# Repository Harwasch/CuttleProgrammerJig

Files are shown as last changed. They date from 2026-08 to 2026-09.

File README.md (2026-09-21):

# Cuttle CANServo_Driver — SWD pogo programming jig

A 3D-printed spring-nest fixture for flashing the Cuttle CAN servo driver
board over SWD, using P50-B1 pogo probes against the seven bare-copper test
points on the underside of the board. No PCB required — five printed parts,
four springs, seven probes and a GH-201 toggle clamp.

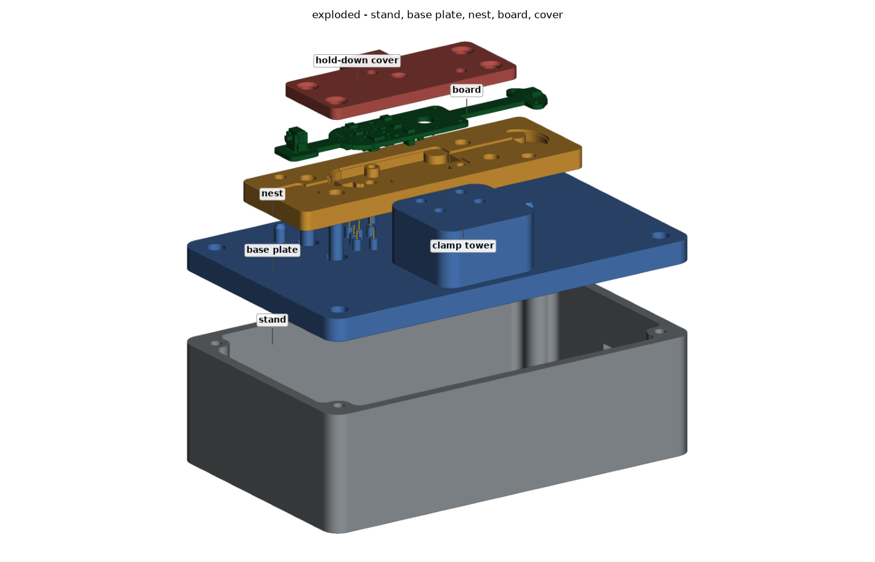
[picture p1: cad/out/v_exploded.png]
assembly


## How it works

The board never has to be pushed onto exposed probe tips by hand:

1. A **nest** floats 3 mm above the base on four springs. The probe tips sit
   **1.8 mm below** the board when the clamp is open, so the board drops in
   freely and locates on two pins through its own 2.2 mm holes.
2. Closing the clamp pushes a **hold-down cover** down onto nine pads that
   land on bare board, driving the nest onto a hard stop.
3. At the stop the nest has travelled exactly 3 mm, which compresses each
   probe **1.20 mm** — 45 % of the P50's 2.65 mm stroke.

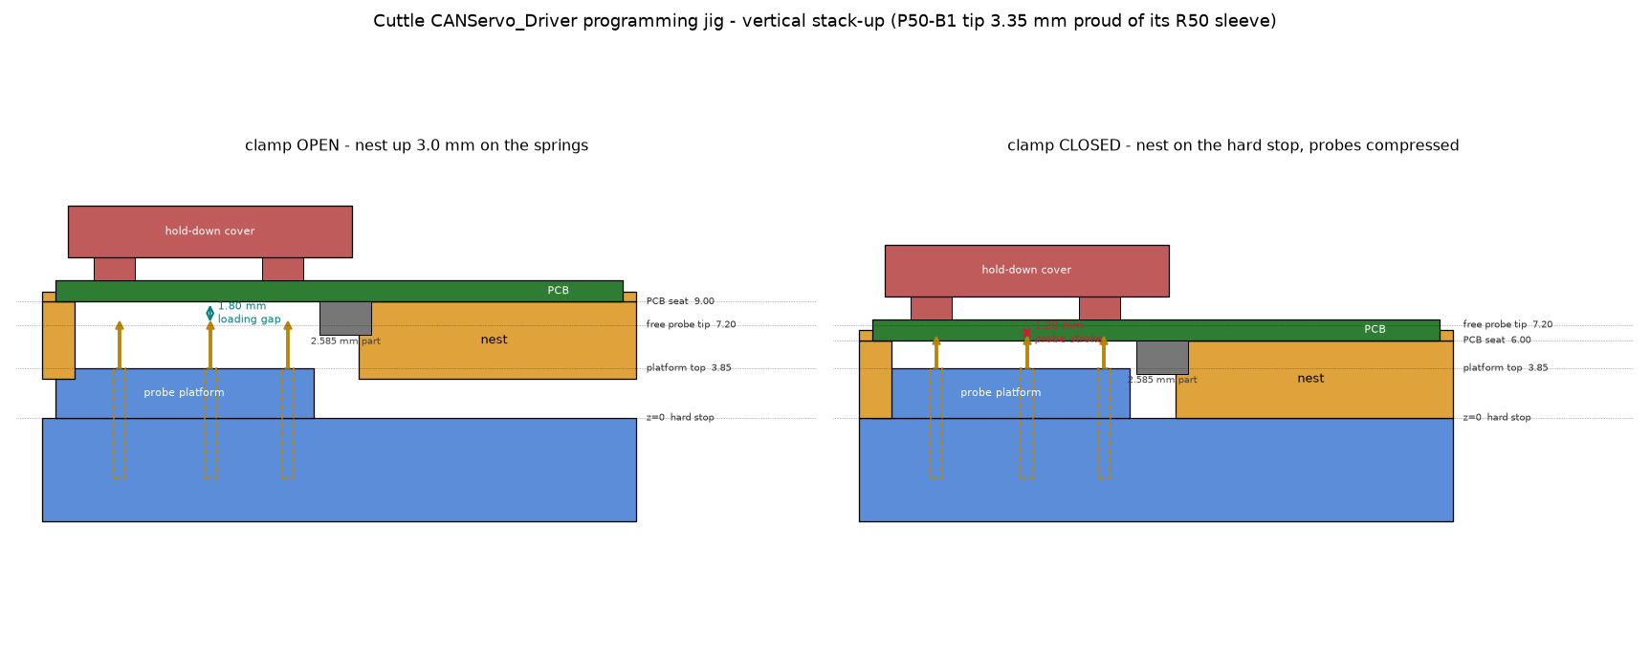
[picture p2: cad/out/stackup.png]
stack-up


## The board

Everything below was extracted from the V0.4 gerbers and the KiCad STEP
export, not typed in by hand — see [`cad/tools/`](cad/tools). The board is a
6-layer rigid-flex, 104.6 × 20.1 mm, 1.627 mm thick, in three rigid sections
joined by two 6 mm flex necks. The jig supports all three flat so the flex is
never bent during programming.

The seven test points are **bare copper discs with solder-mask openings**, not
pad footprints — Ø1.2 mm, all on the bottom layer (L6):

| Net | X | Y | note |
|---|---:|---:|---|
| NRST | −32.25 | +1.70 | 1.42 mm from the board edge |
| GND | −28.25 | −6.30 | |
| SWO | −26.25 | −1.70 | |
| VDD_3V3 | −23.45 | +5.40 | |
| VDD_3V3 | −23.15 | −8.80 | 1.12 mm from the board edge |
| SWDIO | −22.25 | +1.30 | |
| SWCLK | −17.15 | +1.90 | |

Coordinates are in the jig frame: origin at the centroid of the four Ø2.2 mm
holes on the main rigid section, +Y up. Those four holes are the motor /
connector pattern, not board-mounting holes; the jig borrows two of them
(diagonal, 29.6 mm apart) purely to locate the board.

The nest does not try to thread a support surface between the components.
It seats the board on six bosses at its own mounting holes plus the three
sections that carry **no bottom-side parts at all** — the SWD tab and both flex
necks — and drops everything else in one pocket. A boss under the MCU stops
0.1 mm short of the package, backing the board against probe force without
lifting it off its seat. Nothing on the part is thinner than 3 mm.

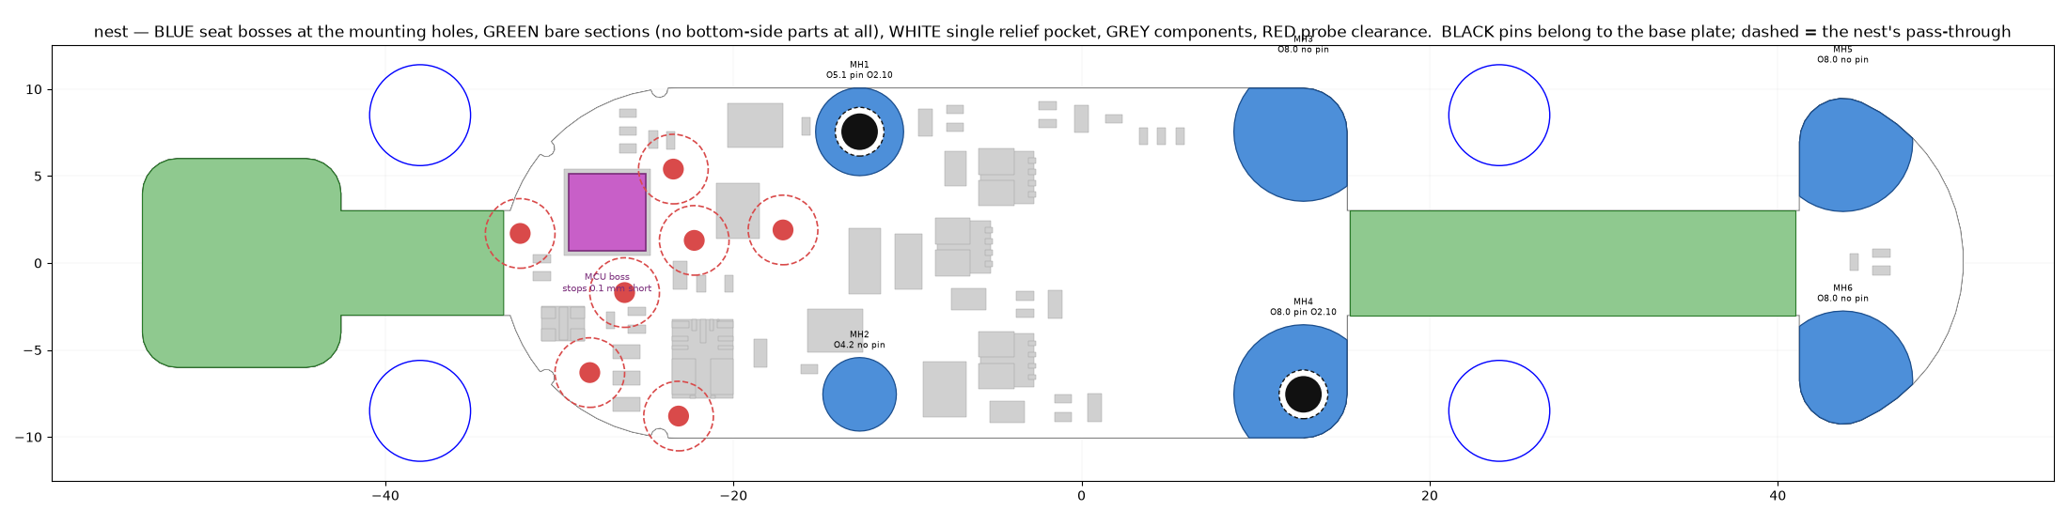
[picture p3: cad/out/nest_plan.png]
nest plan


## Views

| | |
|---|---|
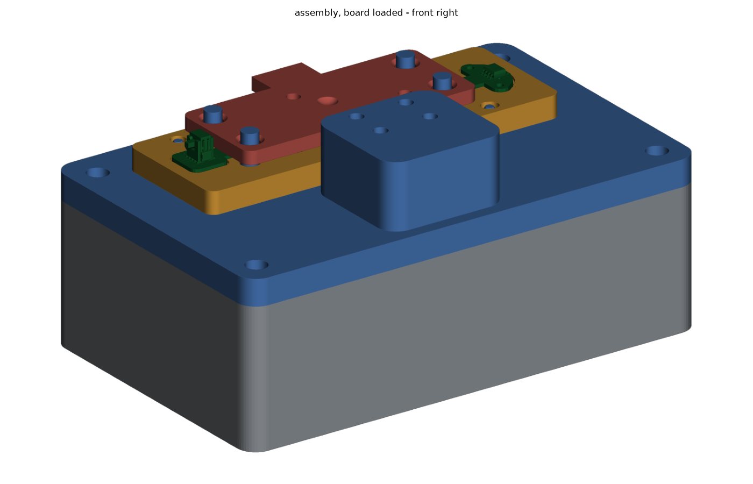
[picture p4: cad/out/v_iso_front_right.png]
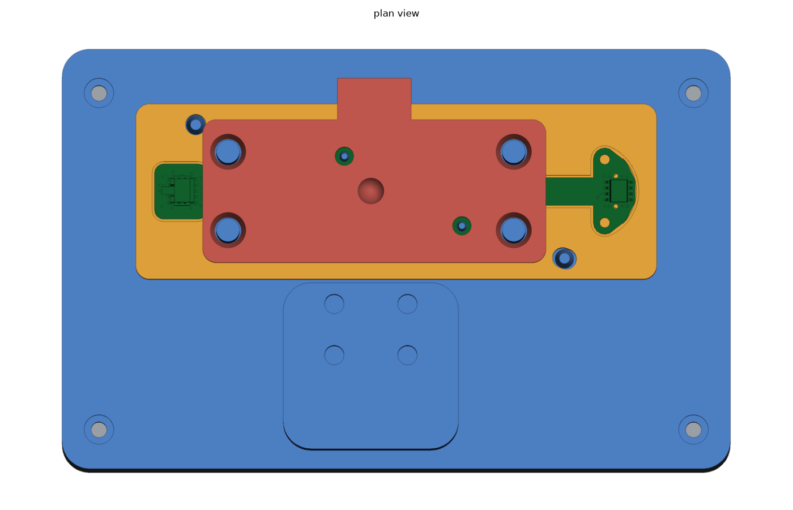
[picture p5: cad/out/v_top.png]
|  |  |
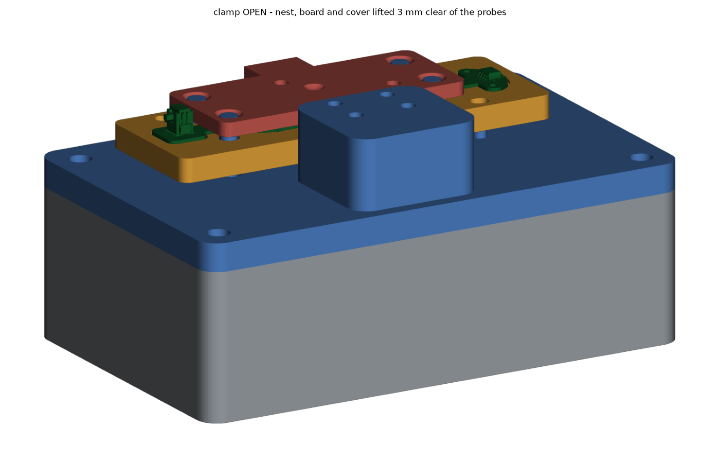
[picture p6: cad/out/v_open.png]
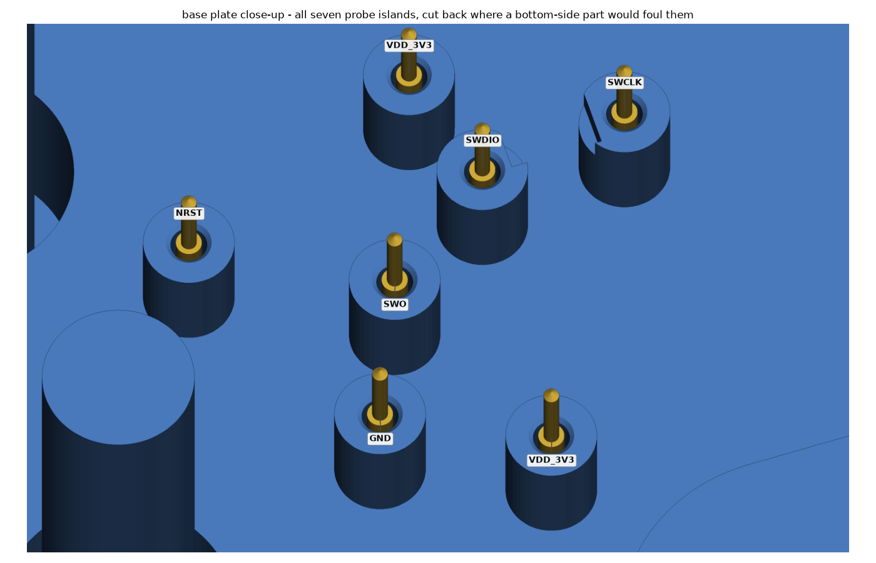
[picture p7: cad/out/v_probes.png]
|  |  |
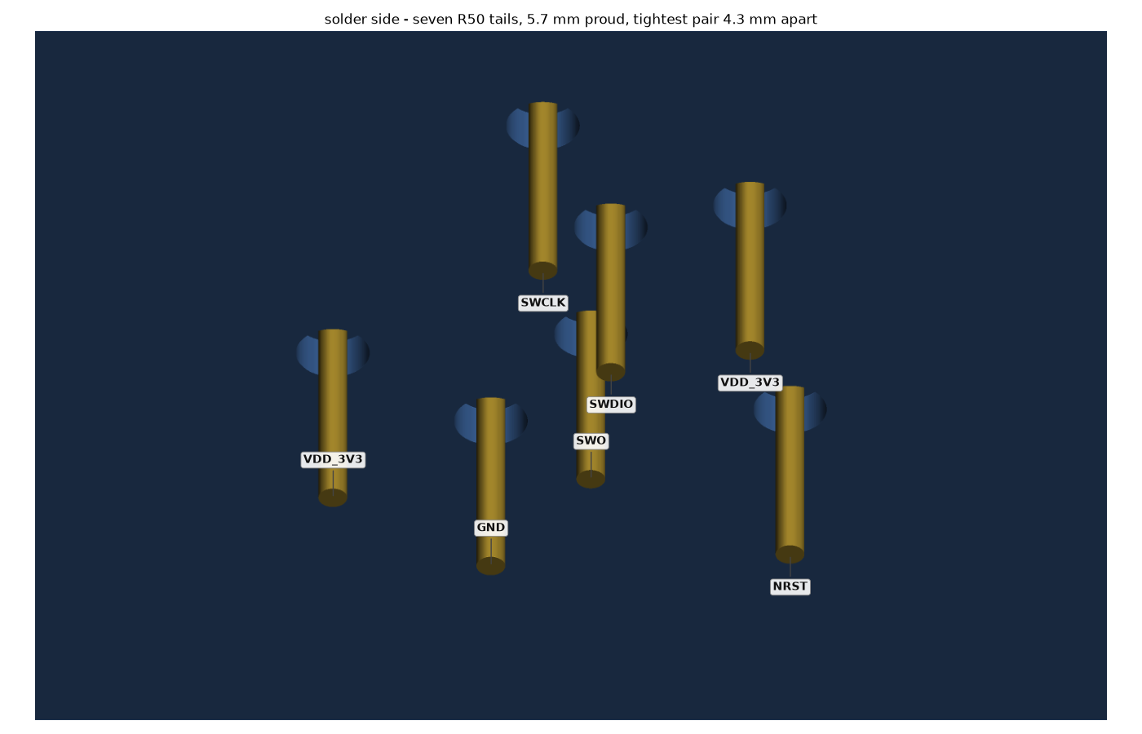
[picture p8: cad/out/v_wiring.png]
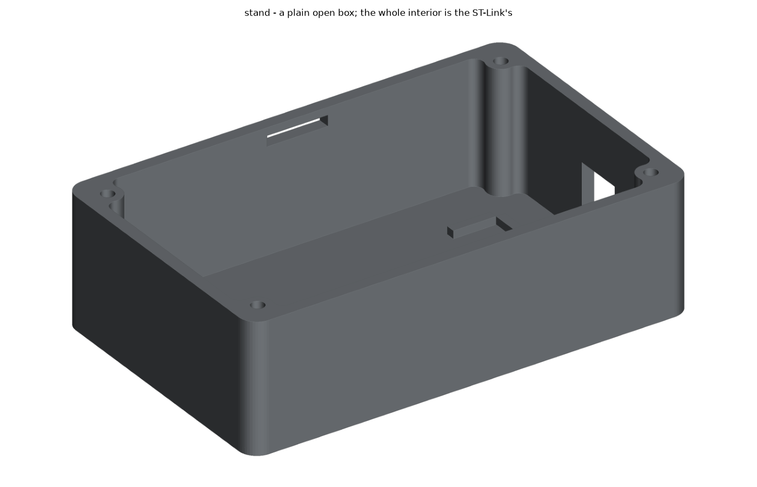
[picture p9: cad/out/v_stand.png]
|  |  |
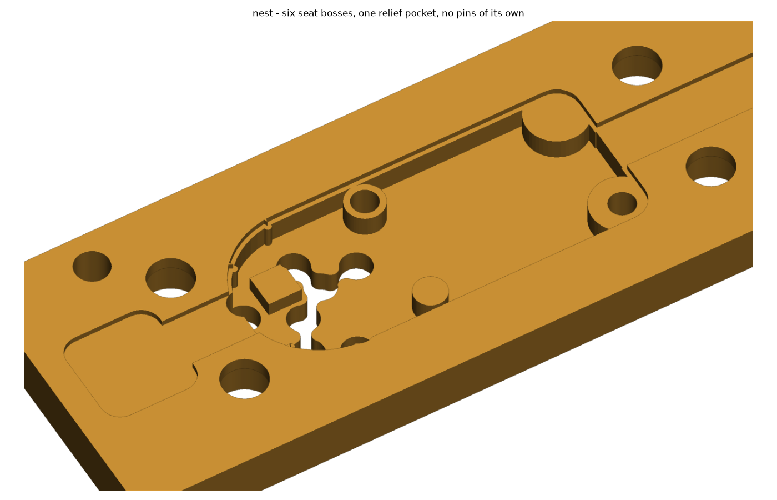
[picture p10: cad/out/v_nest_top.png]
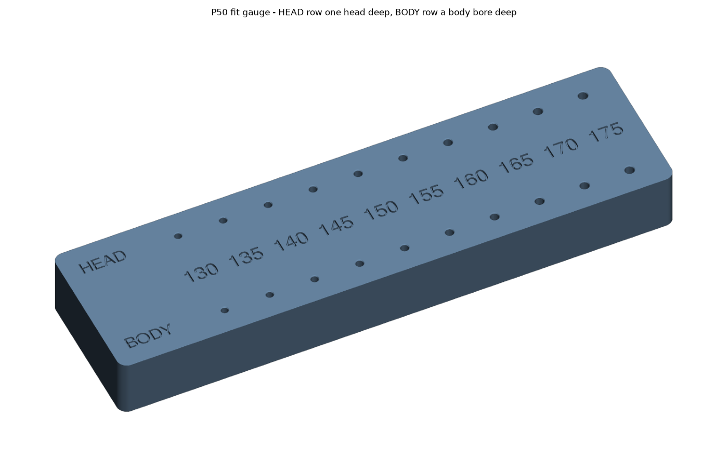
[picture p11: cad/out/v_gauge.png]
|  |  |

`python3 tools/render.py` regenerates all fifteen; `python3 tools/render.py top
probes` does just those. The renderer is a small software z-buffer rasteriser
(orthographic, backface-culled, 2x supersampled, with a depth-discontinuity
outline pass) — a painter's-algorithm sort mis-orders the stand's large flat
faces against the base plate.

## Parts

| Part | Print | Notes |
|---|---|---|
| `base_plate` | flat, features up | The precision part, and the lid of the stand: 7 probe bores, 4 guide posts, 2 stepped board locators, 2 registration pins, spring pockets, and the clamp tower |
| `stand` | as modelled | A plain open box. Its whole 137 × 83 × 40 mm interior is the ST-Link's |
| `nest` | flat | Six seat bosses, one relief pocket, pass-throughs for the locator and registration pins |
| `cover` | pads up | Hold-down; presses only on bare board, rides all four posts, pressed on the centre of the spring quad |
| `fit_gauge` | flat | Calibration coupon; print once to set the probe bore size |

STEP and STL for all of them are in [`cad/out/`](cad/out).

## Getting started

Build instructions, bill of materials, the bore calibration step and the wiring table
are in **[docs/BUILD.md](docs/BUILD.md)**.

To regenerate everything after changing a dimension:

```bash
cd cad
python3 jig.py        # writes STEP + STL into cad/out/
python3 verify.py     # 159 interference, fit and printability checks
```

`verify.py` checks the parts against a keep-out solid built from the real
component heights. That solid uses each component's bounding box, so it is
strictly larger than the parts themselves — a clean result is a proof of
clearance, not a sample of it. `extract_parts.py` refuses to emit a model that
would leave any board-spanning solid unaccounted for, which is what makes the
conservative claim hold. `python3 verify.py --full` re-runs the same checks
against the STEP export's own solids if you want exact shapes rather than
bounding boxes. It takes about twenty minutes.

Both paths test the same population — components. `--full` excludes copper
film (pads, via rings, plating) on the same `FILM_T` rule the extractor uses;
without that it reported the 45 bottom-side copper pads the board rests on as
a 0.28 mm³ interference, which every PCB has and no jig can avoid.

The `--full` path was silently broken until recently: a `Location` on a
`Compound` is ignored by `.intersect()`, so it was measuring the board at its
raw gerber coordinates and reporting four failures that were pure artefact —
with identical volumes before and after a 3 mm lift, which no real boolean can
produce. If you are reading an older revision, do not trust its output.

## Larger pogo pins

`JIG_PINS=P100 python3 jig.py` builds the same jig for a **P100-B1 probe in an
R100-4S receptacle** instead of the default P50/R50 pair, into `cad/out/p100/`.
It is a new `base_plate`, `stand` and `fit_gauge`; the `nest` and `cover` carry
straight over. Its gauge also gave the design a second hole-shrink calibration
point — 0.10 mm at Ø2.0 against 0.22 mm at Ø1.2 — so the print model
interpolates with diameter instead of using one constant. Both variants build and verify from the same code, and
`cad/tools/compare_families.py` reports which parts actually differ. See
[docs/BUILD.md](docs/BUILD.md) for why the bigger pin also moves the ST-Link.

## Magnet test fixture

[`magfixture/`](magfixture) is a separate fixture for the same board: it holds
it flat and presents a spinning magnet to the AS5600L rotary encoder and a
magnet adjustable from 1 to 13 mm to the linear hall sensor. It reuses this
package's board geometry and print model rather than keeping its own copy.

## Board source files

`cad/ref/` holds the inputs the extractors read — the V0.4 gerbers and the
KiCad STEP export — and is **git-ignored on purpose**: this repository is
public and the servo board repository is not. Copy them in locally before
re-running the extractors. The derived `board_geometry.json` and
`board_parts.json` that `jig.py` actually builds from are committed.

## Retargeting to a new board revision

```bash
cd cad/tools
python3 extract_board.py   # outline, cutouts, test points  <- gerbers
python3 extract_parts.py   # component keep-outs            <- STEP
cd .. && python3 jig.py && python3 verify.py
```

Nothing in `jig.py` hard-codes board geometry; it all comes from
`board_geometry.json` and `board_parts.json`.

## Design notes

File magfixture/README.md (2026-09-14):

# Magnet test fixture — Cuttle CANServo_Driver V0.4

Holds the board flat and presents a magnet to each of its two magnetic
sensors, so both can be exercised on the bench.

| sensor | package | centre | package top |
|---|---|---|---|
| **AS5600L** rotary encoder | SOIC-8 | (+46.81, +0.10) | 1.838 mm above the board |
| **SOT-23** linear hall | 3-pin | (−23.25, +0.07) | 1.285 mm above the board |

Both positions are **measured**, not transcribed: the KiCad STEP export carries
each component's footprint name as a label, and `tools/find_sensors.py` reads
them straight out of it. The package *heights* come from `cad/board_parts.json`
— the same keep-out data the interference checks use — so the airgap the
fixture builds and the airgap the checks measure cannot disagree.

## What it does

**Encoder.** A Ø6 × 2.5 mm diametric magnet in a rotor, journalled directly
over the package and spun by finger. The airgap is **1.00 mm** face to package,
inside the AS5600 datasheet's 0.5–3.0 mm window, and it is set by the rotor's
own shaft length against a knob that lands on the journal hub — nothing to
adjust, nothing to measure. The magnet stays within **0.242 mm** of the die
centre worst case, inside the datasheet's ±0.25 mm.

**Linear hall.** A magnet on a sleeve running on one column, adjustable from
**1 mm to 13 mm** face-to-face.

It takes **any of three magnets** — Ø6, Ø10 or Ø13 — all seating on the same
face datum. The Ø13 presses straight into the sleeve pocket; the smaller two go
in via a press-in adapter ring. A stepped pocket would have been simpler but is
exactly wrong here: the smallest magnet would end up highest, and it is the one
that has to reach 1 mm from the package. A Ø4 hole through the pocket ceiling
pushes any of them back out — you cannot pull a neodymium magnet out of a blind
hole.

## What changed, and why

**One part, not three.** The plate, the hall column and the encoder portal are
now a single printed body. The encoder stand used to bolt on, which was a thing
to lose and a stack-up between the magnet and the board.

**A column, not posts.** Two Ø6 × 30 mm free-standing cylinders snapped at the
root, and they were always going to: a printed cylinder lays its layer bonds
square across the bending load, offers 42 mm³ of section modulus between them,
and cannot be flared into the plate. The 14 × 10 mm column carries **228 mm³**
— 1.09 MPa at the root under a 10 N shove at the top of its travel, a 23×
margin on PETG's layer-bond strength — resists twist without needing a second
member, and sits on a gusset that spreads the root stress instead of
concentrating it in one layer line.

**A portal, not a cantilever.** The encoder reach used to be a 9 mm ledge
anchored on one side. Two walls carry a deck, so the deck's underside is a true
bridge anchored at both ends.

**A dowel and a diamond on the lobe.** The lobe pins needed a pin radius of
freedom along the line joining them. *Moving* them together by that much does
not give it — the lobe's hole pitch is 13.723 mm and fixed inside the rigid
lobe, the pins print Ø2.10 in a routed Ø2.20, so a 1.010 mm pitch change leaves
the second pin missing its hole by 0.960 mm and the lobe will not go on at all.
Dowel-and-diamond does give it: **MH5 is a round pin and is the datum**, MH6 is
relieved to 1.09 mm along the pitch line and stays full width across it, so the
pair floats **±0.555 mm** on pitch while still stopping the lobe rotating.

And since the main section is on the far side of a flex neck — where the
lamination, not the drawing, decides where it ends up — the **lobe** is the
datum and MH1/MH4 are undersize (Ø1.80, 0.20 mm radial) so the main section
follows it instead of fighting it. The encoder is the tight requirement; a hall
magnet 6 to 13 mm across does not care about a fifth of a millimetre.

## Bill of materials

| Qty | Item | Notes |
|---:|---|---|
| 1 | Ø6 × 2.5 mm magnet, **diametric** | encoder — must be diametrically magnetised or the AS5600 reads nothing useful |
| 1 | Ø6 × 2.5, Ø10 or Ø13 magnet, **axial** | linear hall |
| 1 | M3 heat-set insert, 4 mm | sleeve clamp |
| 1 | M3 × 16 thumbscrew | clamps the sleeve to the column |

## Parts

| Part | Print | Notes |
|---|---|---|
| `fixture_body` | flat, features up | Plate, relief pocket, four locating pins, hall column, encoder portal |
| `rotor` | **inverted**, knob down | Ø9 body, Ø6 magnet pocket |
| `hall_sleeve` | flat, arm underside down | Rectangular bore, Ø13 pocket opening downward |
| `ring_10`, `ring_6` | flat | Press-in adapters |
| `gap_gauge` | flat | One tongue per separation |

No supports on anything. Worst bridge is **11.0 mm of half-span** (the portal
deck, anchored on both walls); nothing anywhere is an unanchored ledge.

## Assembly

1. Press the encoder magnet into the rotor until its face is flush with the
   rotor's bottom. **Check the polarity is diametric** — it should attract and
   repel a second magnet around its circumference, not through its faces.
2. Drop the rotor down through the portal's journal from above. The knob cannot
   follow it through; it lands on the hub and sets the airgap.
3. Melt the M3 insert into the sleeve's clamp boss and fit the thumbscrew.
4. Press the hall magnet into the sleeve pocket, face flush with the sleeve's
   underside — directly for Ø13, through `ring_10` or `ring_6` otherwise. Press
   the ring in flush first, then the magnet into the ring.
5. Slide the sleeve down onto the column.

## Using it

Lift the rotor out, slide the board's lobe under the portal deck, and let the
board down onto its four pins — MH5 first, which is the datum. Drop the rotor
back in.

**Encoder:** turn the knob. Nothing to set.

**Linear hall:** slacken the thumbscrew, slip the gap gauge's step between the
magnet face and the package, let the sleeve down onto it, tighten, withdraw the
gauge. That sets the separation by a printed dimension you can check with
calipers rather than by reading a scale — and it makes sleeve tilt irrelevant
to the number you end up with. Steps are 1, 2, 3, 4, 5, 6, 8, 10 and 13 mm.

To take the board out: lift the rotor, lift the board clear of its pins (3.6 mm,
against 6.5 mm of headroom under the deck), slide it out in −X.

## Checks

```bash
cd magfixture
python3 fixture.py      # STEP + STL into out/
python3 verify.py       # 62 checks
python3 tools/render.py
```

`verify.py` measures sensor targeting, sleeve travel and its clearance to the
PCBA across the whole sweep, every fit as printed, board seating, and
overhangs in each part's print orientation. It shares the board geometry and
the print model with the programming jig in [`../cad`](../cad) rather than
keeping a second copy that can drift.

The printability check tells **bridges from cantilevers**, which the jig's
version does not: it collects overhang area per tessellated triangle, takes the
part's own plan section 0.5 mm below as the support, and counts a patch as
bridged only where it lies inside the convex hull of that section. A bridge is
anchored at both ends and the filament goes into tension; a cantilever has a
free end and curls after a few millimetres. Treating both as "the widest
downward face" is what let a 9 mm one-sided ledge through, and what let the gap
gauge's tongues stick 14 mm into thin air.

## Measure these before printing

`HALL_MAG_T_MAX` (8 mm) is the deepest hall magnet the pocket takes — check
yours fits, since you may use a Ø10 or Ø13 of unknown thickness. Everything
else is driven by the board's own STEP or by the AS5600 datasheet.

If your board drops onto full-size pins at both lobe holes, set
`LOBE_PIN_PULL_IN = 0.0` in `mag_params.py`: MH6 becomes a round pin too, and
the lobe is then located to 0.05 mm instead of 0.555 mm.

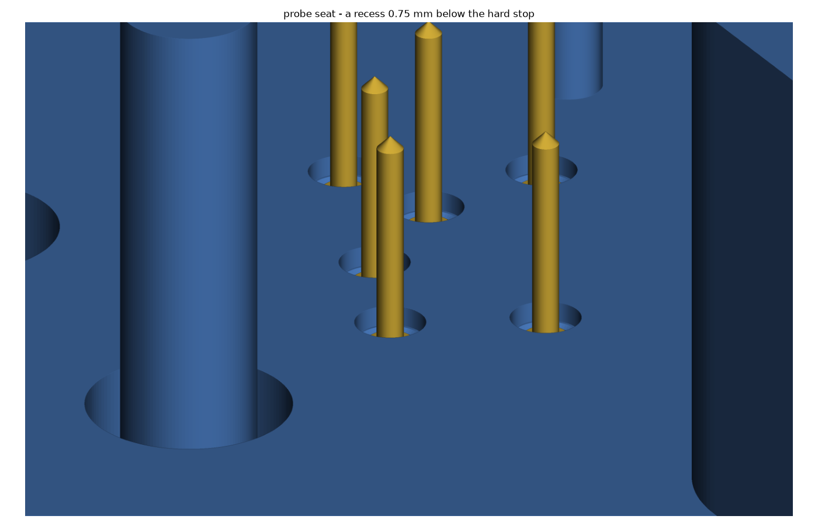
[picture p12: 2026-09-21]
cad/out/p100/v_seat.png

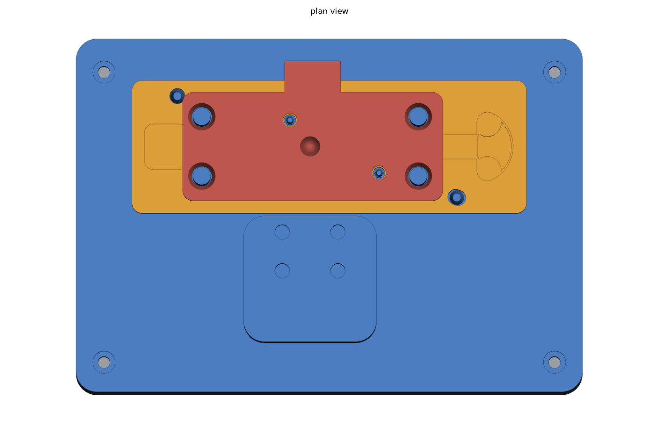
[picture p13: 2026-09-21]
cad/out/p100/v_top.png

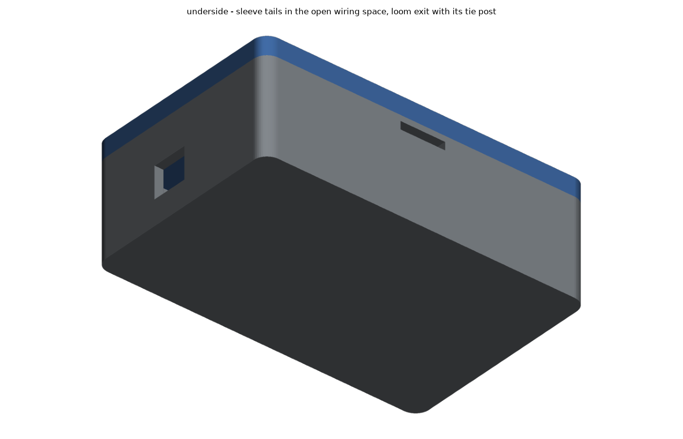
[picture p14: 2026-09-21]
cad/out/v_underside.png

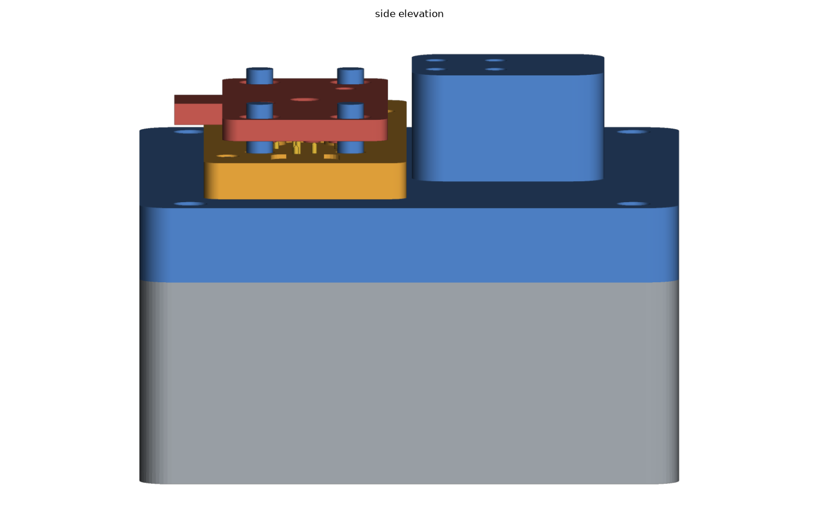
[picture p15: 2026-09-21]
cad/out/p100/v_side.png

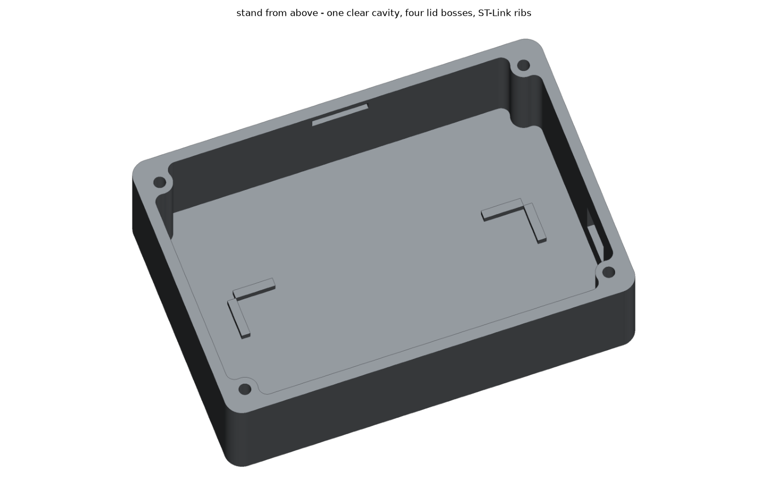
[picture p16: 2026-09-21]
cad/out/p100/v_stand_top.png

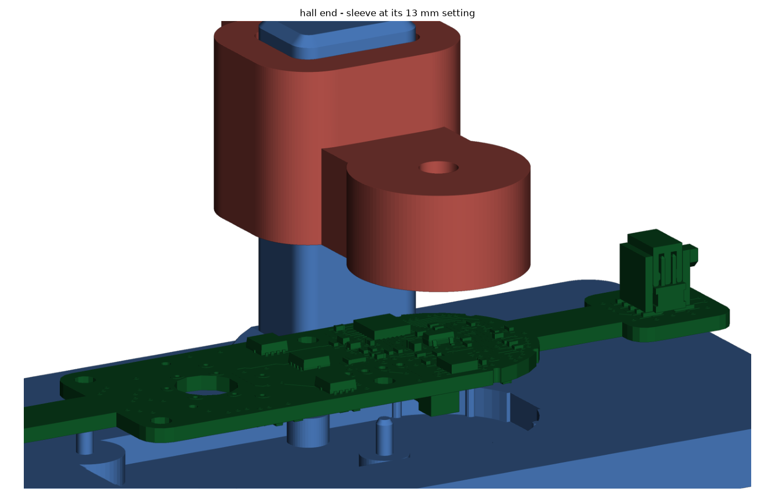
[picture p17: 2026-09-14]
magfixture/out/v_hall_far.png

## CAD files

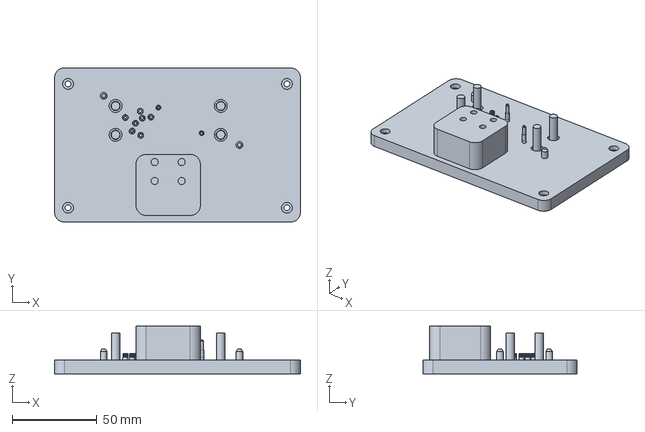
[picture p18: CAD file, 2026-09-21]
cad/out/base_plate.step
145.0 x 91.0 x 28.0 mm

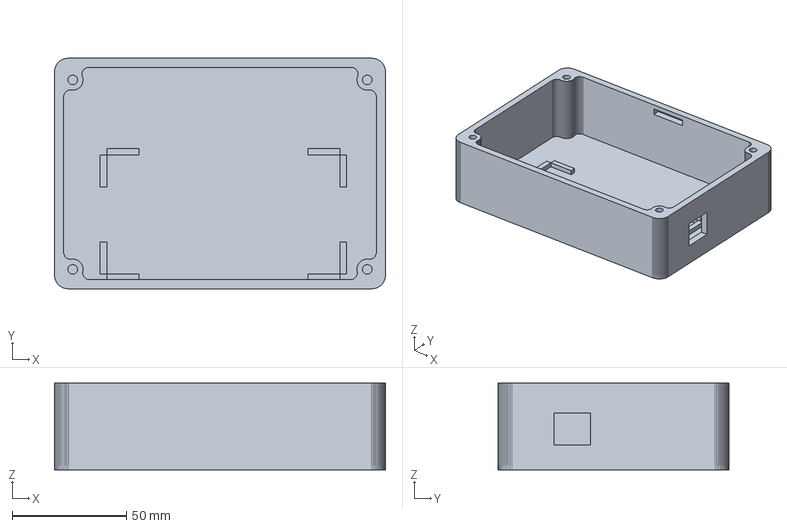
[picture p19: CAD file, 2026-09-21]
cad/out/p100/stand.step
145.0 x 101.0 x 38.0 mm

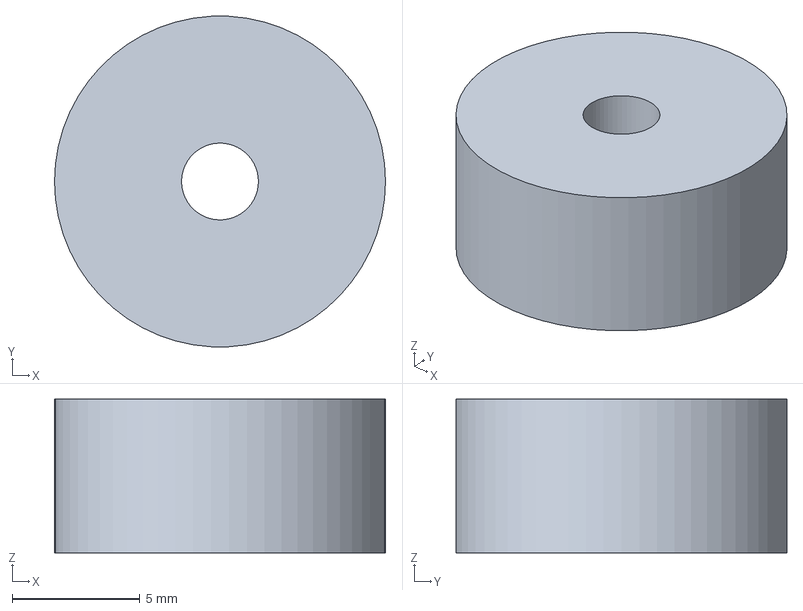
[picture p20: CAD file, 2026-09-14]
magfixture/out/ring_6.step
12.9 x 12.9 x 6.00 mm

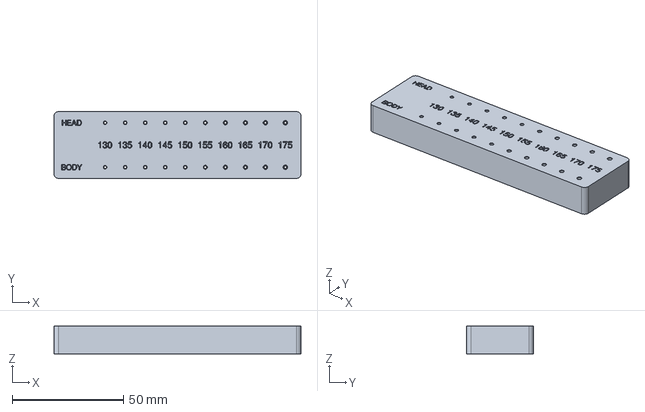
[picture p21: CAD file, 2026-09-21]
cad/out/fit_gauge.step
111.0 x 30.0 x 12.5 mm

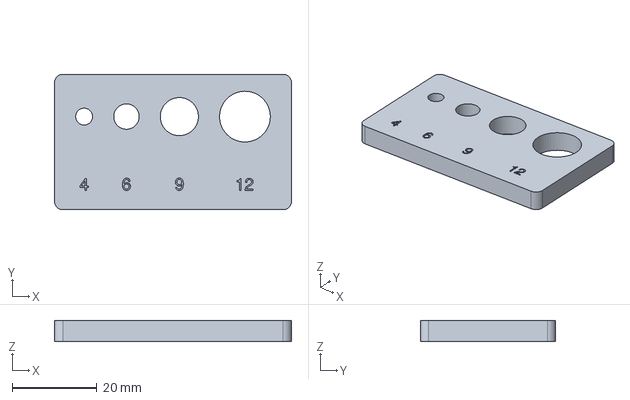
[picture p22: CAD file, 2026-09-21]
cad/out/p100/shrink_gauge.step
56.0 x 32.0 x 5.00 mm

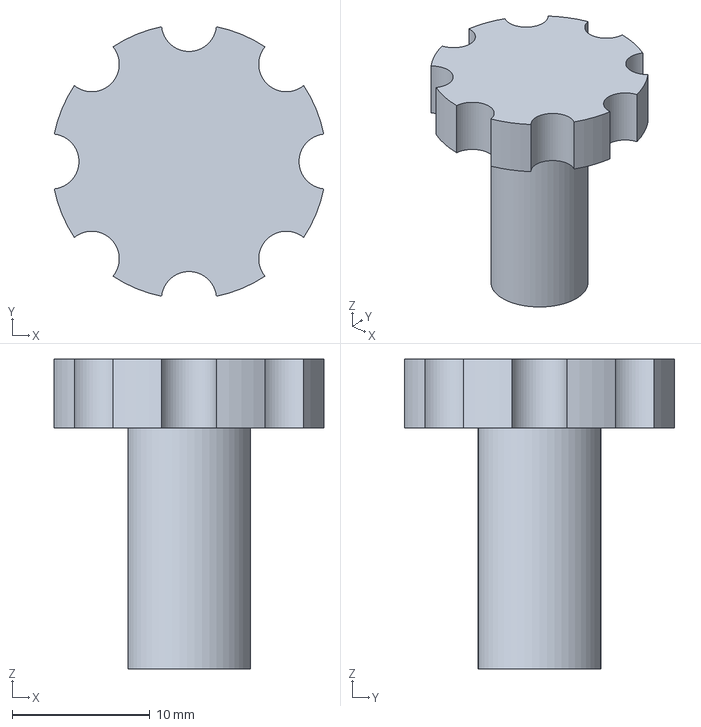
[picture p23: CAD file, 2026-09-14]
magfixture/out/rotor.step
19.6 x 19.6 x 22.5 mm

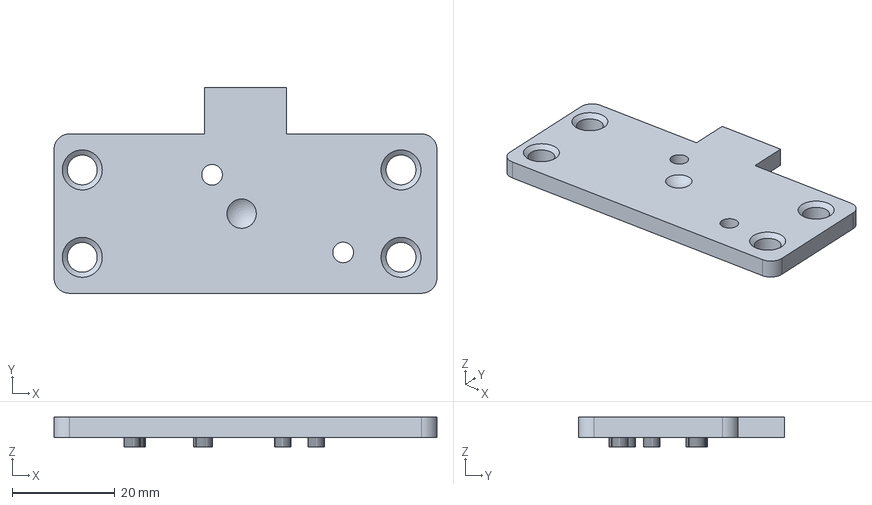
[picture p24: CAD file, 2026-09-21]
cad/out/p100/cover.step
74.5 x 40.0 x 5.80 mm

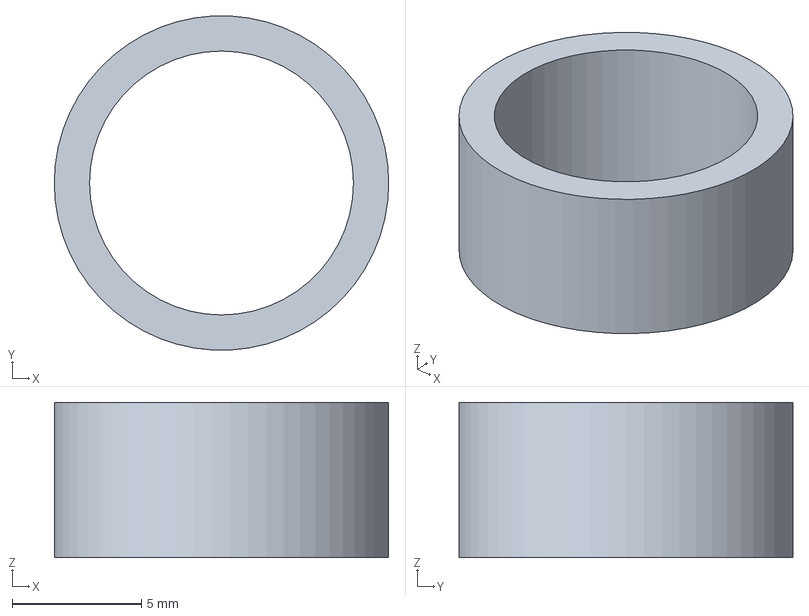
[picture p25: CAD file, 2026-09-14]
magfixture/out/ring_10.step
12.9 x 12.9 x 6.00 mm

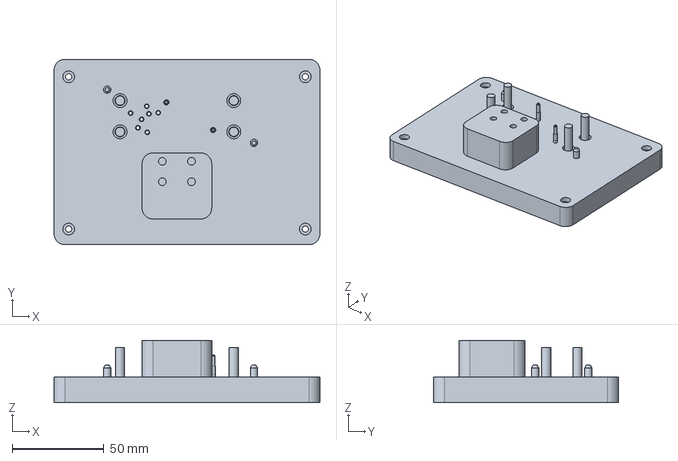
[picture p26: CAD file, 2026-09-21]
cad/out/p100/base_plate.step
145.0 x 101.0 x 34.0 mm

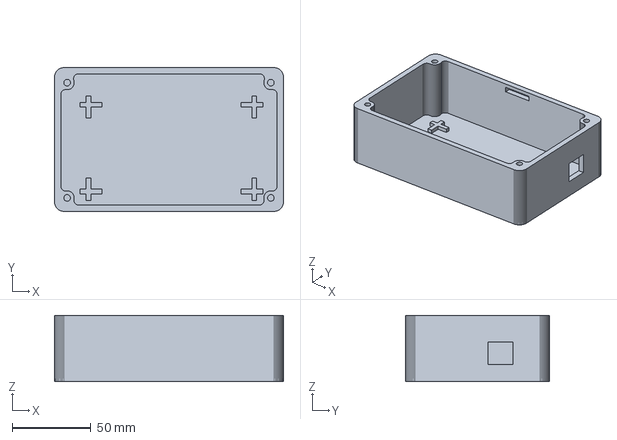
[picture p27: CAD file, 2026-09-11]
cad/out/stand.step
145.0 x 91.0 x 42.0 mm

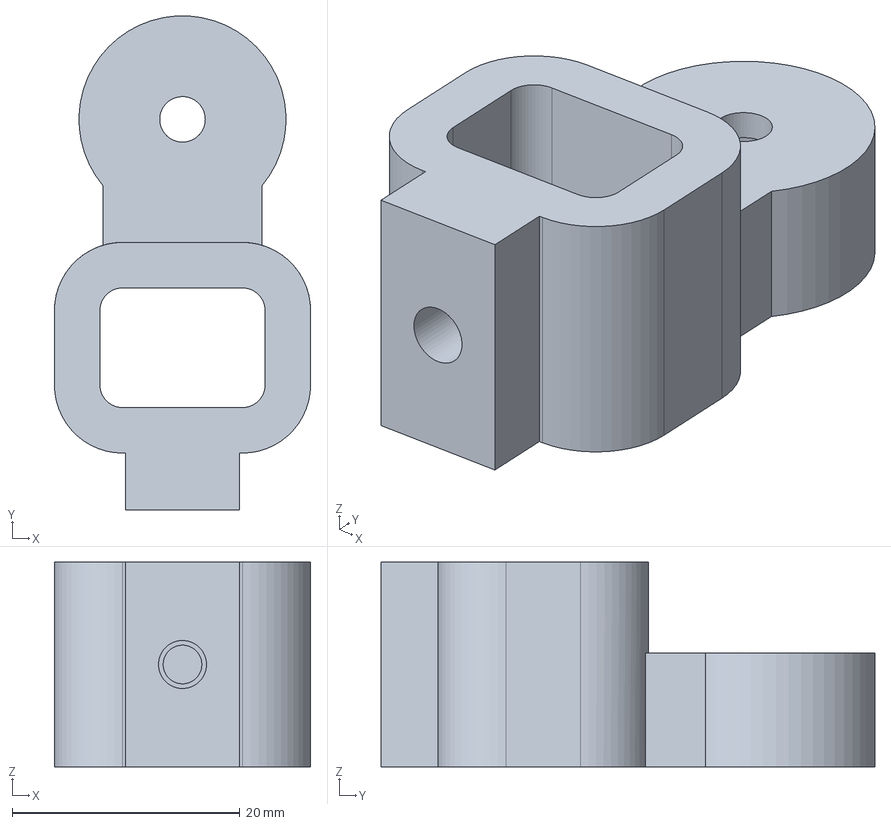
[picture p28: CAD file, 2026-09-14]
magfixture/out/hall_sleeve.step
22.5 x 43.4 x 18.0 mm

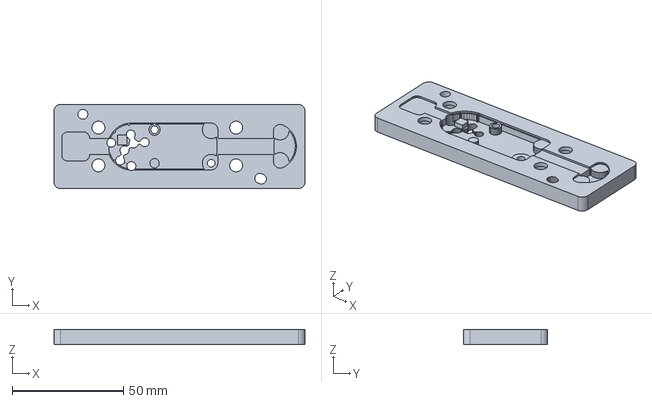
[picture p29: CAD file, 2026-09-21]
cad/out/p100/nest.step
113.0 x 38.0 x 6.80 mm

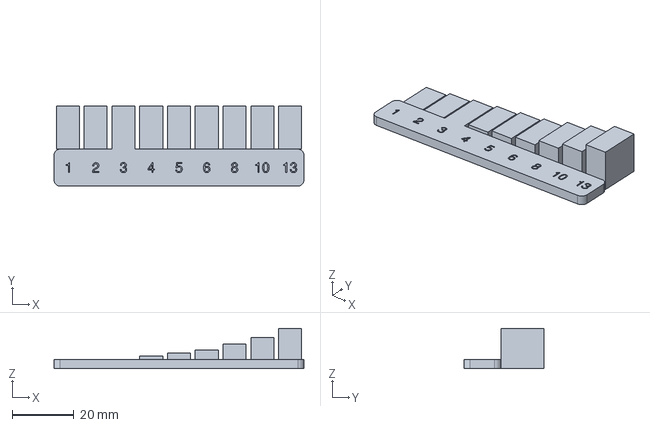
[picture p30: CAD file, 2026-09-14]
magfixture/out/gap_gauge.step
81.0 x 26.0 x 13.0 mm

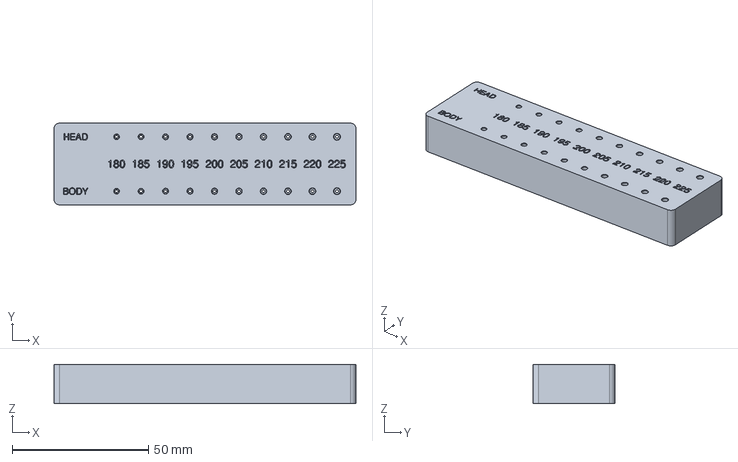
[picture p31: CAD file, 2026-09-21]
cad/out/p100/fit_gauge.step
111.0 x 30.0 x 14.5 mm

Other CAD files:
cad/out/shrink_gauge.step
cad/out/cover.step
cad/out/nest.step
magfixture/out/fixture_body.step
cad/out/base_plate.stl
cad/out/fit_gauge.stl
cad/out/p100/base_plate.stl
cad/out/p100/cover.stl
cad/out/p100/fit_gauge.stl
cad/out/p100/nest.stl
cad/out/p100/shrink_gauge.stl
cad/out/p100/stand.stl
cad/out/shrink_gauge.stl
cad/out/stand.stl
magfixture/out/fixture_body.stl
magfixture/out/gap_gauge.stl
magfixture/out/hall_sleeve.stl
magfixture/out/ring_10.stl
magfixture/out/ring_6.stl
magfixture/out/rotor.stl

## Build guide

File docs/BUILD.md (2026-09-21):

# Building the jig

## Bill of materials

| Qty | Item | Notes |
|---:|---|---|
| 7 | P50-B1 spring test probe | Ø0.68 mm tube, 16.35 mm, 30° spear tip, 75 g |
| 7 | R50-2S receptacle | Ø0.86 mm body, 17.5 mm, solder slot |
| 1 | `fit_gauge` print | calibration coupon, printed once |
| 4 | Compression spring, 0.6 × 7 mm | from the kit — **select on solid height, not free length: it must stack shorter than 10 mm** |
| 1 | GH-201 horizontal toggle clamp | 75 × 25 × 17 mm, 27 kg |
| 8 | M3 heat-set insert, 4 mm | Kadrick-type, Ø4.5 knurl / Ø3.9 tip — 4 into the clamp deck, 4 into the stand's corner bosses |
| 4 | M3 × 12 socket screw | toggle clamp to the deck |
| 1 | ST-LINK/V2 | genuine, in its case — lives in the bay under the deck |
| 1 | 20-pin IDC socket + ribbon, **or** 6 × female jumper leads | probe tails to the ST-Link header |
| 1 | small zip tie | strain relief on the 3.3 V feed |
| — | 7 × silicone wire, **30 AWG** | probe tails; see Wiring |

| 4 | M3 × 12 socket screw | base plate to stand |

### The ST-Link bay

`STLINK_CASE` in [`cad/params.py`](../cad/params.py) is **100 × 50 × 30 mm**,
plus `STLINK_HEADER_ROOM` (15 mm, for the 20-pin ribbon) and `STLINK_USB_ROOM`
(12 mm, for the plug and its boot). That makes a **127 × 52 × 32 mm** cavity in
a 137 × 83 × 40 mm interior, so there is room to spare in every direction.

The case drops in from above before the lid goes on — no slide-in opening to
line up — and four ribs on the floor stop it wandering. Only the USB cable
leaves, through a 16 × 14 mm hole in the +X wall.

Trim `HEADER_ROOM` and `USB_ROOM` once you can see how your cables actually
bend. Both are parameters; only the stand reprints, and the stand carries
nothing precise.

Print everything in **PETG**, not PLA — the jig sits under continuous spring
load and PLA creeps, and PETG takes heat-set inserts well. ABS also works if
you would rather, but nothing here needs its temperature resistance.

### Which printer

Every part fits every machine you have — the two largest are both
145 × 91 mm in plan, well inside an X1C's 256 mm bed, let alone an H2D or H2C.
So build volume is not the deciding factor; two other things are.

**Keep the fit gauge and the base plate on the same machine, nozzle and
filament.** The gauge exists to measure *that machine's* hole shrinkage. Print
the gauge on one printer and the plate on another and the calibration is void —
this matters more than which printer you pick.

**The base plate is the only part where precision matters.** It carries the
seven Ø1.2 mm probe bores, four guide posts, two stepped board locators and two
registration pins, and it is 122 cm³. Run it at 0.12–0.15 mm layers on whichever
machine you trust most for small features. If you have a **0.2 mm nozzle**, this
is the part worth the extra time.

**The stand is 110 cm³ of plain walls** with no precision requirement at all —
four walls, a floor, four corner bosses and two holes. Put it on whichever
machine is fastest. If the bore calibration turns out wrong, only the plate
reprints.

The bosses are not cylinders sitting against the walls: the wall ring and the
four bosses are built as one 2D outline and morphologically closed, so each
boss blends into its corner on a 3 mm fillet. Left as bare cylinders, two of
them met the wall exactly tangentially — a wedge closing to zero degrees, which
no nozzle can fill — and the other two stood 1 mm clear of it as free pillars
with a slot behind. `verify.py` now checks the cross-section is one connected
piece and that re-closing it adds nothing.

I have no basis for ranking the H2C, H2D and X1C against each other for
dimensional accuracy on features this small, so I would not choose between them
on that — pick the one whose profile you have most confidence in, and let the
fit gauge tell you what it actually produces.

## Print settings

| Setting | Value | Why |
|---|---|---|
| Layer height | 0.15 mm | probe bores and the 0.8 mm nest lip |
| Perimeters | 4 | posts, probe islands and locator pins are small and loaded |
| Infill | 30 % | |
| Hole horizontal expansion | **0** | you calibrate with the gauge instead |
| Supports | **none** | see below |

Orientation: `base_plate` flat on its underside (posts, pins and clamp tower
all pointing up), `stand` on its own base, `nest` lip up, `cover` **pads up**
(inverted from how it is modelled).

In those orientations every feature is a vertical wall or a vertical hole. The
largest unsupported span anywhere is **12.0 mm**, the roof of the clamp tower's
cavity, which bridges without help. The next is the cover's spindle dish at
5.7 mm. `verify.py` measures the largest circle that fits inside every downward
face — the distance filament actually spans — and requires it to be under
25 mm. It considers **every** face whose normal falls past 45°, not just
exactly-horizontal planes: filtering on planes alone made the dimple invisible,
and it could be opened into a hole clean through the cover with no complaint.

## Calibrate the probe bores first

The probe bores print to final size — but FDM renders a small vertical hole
undersize by an amount specific to your printer, nozzle, material and speed, so
you calibrate once. **Calibrate with the RECEPTACLE**, which is what sits in the
bore. Reading the gauge with the probe in hand instead is the one mistake that
has actually been made here, and it cost a base plate: the P50-B1's barrel is
Ø0.68 and the R50-2S's head is Ø0.98, so the answer came out 0.30 mm small and
no sleeve would seat.

1. Print `fit_gauge.stl` (111 × 30 × 12.5 mm, about 35 minutes) in the **same material and profile** you will use for
   the base plate. Two rows of ten, labelled in hundredths of a millimetre:

   | row | depth | how to read it | sets |
   |---|---|---|---|
   | **HEAD** | one receptacle head | push the sleeve in **head first**; the smallest bore the head goes fully into with a firm thumb push, the step down to the body ending flush with the face | `PIN_BORE_D` |
   | **BODY** | one body bore | push the sleeve in **tail first**; the smallest bore the body slides down without force | `PIN_BODY_BORE_D` |

   Two rows because the plate needs two bores and at this size they cannot be
   derived from one another: shrink changes fast enough down here that the
   counterbore and the body bore end up barely 0.05 mm apart as modelled, which
   is less than the uncertainty in either.

   Each row is bored to the depth of the feature it stands for, because a
   deeper hole tapers more and reads tighter. Every bore has an eject hole
   through the back — a press fit in a blind hole otherwise stays there.

2. The answer must have a bore too tight below it **and** one visibly loose
   above it. If the sleeve only enters the largest, the range has not bracketed
   your printer: shift `GAUGE_BORES` up and print again. The P50 range steps
   1.30 to 1.75 and the P100 range 1.80 to 2.25.

3. Put the two numbers in `PIN_BORE_D` and `PIN_BODY_BORE_D` in
   [`cad/params.py`](../cad/params.py), add the point
   `(PIN_BORE_D, PIN_BORE_D − your head diameter)` to `HOLE_SHRINK_CAL`, and
   run `python3 jig.py`.

### Getting the receptacles in

They go in tail first, and a 0.86 mm brass tube buckles easily, so do not pinch
the tube — push on the head with something flat. The bore is a 0.020 mm radial
slip over 8 mm, which is a firm push, not a fight; if it fights you, the bore
is undersize and the gauge is telling you so. A cone leads from the counterbore
into the body bore so the tube cannot catch square on the step.

### If the P50 bores will not come out

At Ø0.98 a printed hole is two and a half nozzle widths across and the printer
is removing something like 40 % of it. If the gauge will not give you a clean
answer, the bores are **drillable, and the geometry is already sized for it**:
Ø1.00 and Ø0.90 are stock drill sizes, and they land exactly where the design
wants them — a Ø1.00 counterbore on a Ø0.98 head is 0.01 mm of slip, a Ø0.90
body bore on a Ø0.86 body is the 0.02 mm the design asks for, and a Ø0.98 head
still cannot enter a Ø0.90 bore, so the depth stop survives. Print the plate,
run both drills down each bore by hand using the printed hole as the pilot, and
the fit stops depending on the print model at all.

The P100 family does not have this problem — Ø1.90 and Ø1.71 are comfortable
for FDM — which is worth knowing if you have both sets of pins.

### Hole shrink is a function of diameter AND depth

The P50 gauge's two rows are the same diameters at different depths, so it
measured both at once:

| bore | depth | part that just entered | shrink |
|---|---|---|---|
| Ø1.35 | 2.5 mm | Ø0.98 R50 **head** (1.30 not quite) | **0.37** |
| Ø1.35 | 8.0 mm | Ø0.86 R50 **body**, a little play (1.30 not at all) | **0.45** |
| Ø2.00 | 7.5 mm | Ø1.90 R100 head | **0.10** |

The first two differ only in depth: **5.5 mm deeper costs 0.08 mm of printed
diameter**. Ignoring that is what buckled a batch of receptacles — the body
bore was offset from the counterbore on the assumption that both shrank the
same, which put an *interference* fit 8 mm long on a 0.86 mm brass tube.

Both bores are now solved at their own depth. On the P50 they land on the same
**Ø1.35 modelled** and print **Ø0.98** and **Ø0.90** — exactly what the two
gauge rows read. So on this printer **the step that stops the sleeve is
produced by depth, not by modelled diameter**, and `verify.py` measures it as
printed rather than assuming it. That is a real dependency: a printer without
the depth effect would have no step at all, and `PIN_BORE_D` would have to be
opened up to create one.

An earlier Ø1.20 reading is withdrawn — it was taken with the probe in hand
rather than the receptacle, and the probe's barrel is Ø0.68 against the
receptacle's Ø0.98 head, so it answered a different question by 0.30 mm.

The depth term rests on that one pair of rows. **Nothing has been measured at
Ø4 and up**, which is where the guide posts, the registration pins, the insert
holes and the magnet fixture's rotor journal live. Those use
`PRINT_HOLE_SHRINK`, a separate constant at 0.22, deliberately not tied to the
calibration list — every one of those features has been printed at that figure
and works, and a 40 % small-hole loss has no business up there. Shrink cannot
rise again as the hole grows, so the honest bracket is 0 to 0.10 and
`verify.py` checks across it.

To close that, print **`shrink_gauge`** (56 × 32 × 5 mm, about 15 minutes):
four plain through holes modelled at Ø4, Ø6, Ø9 and Ø12 with the number
engraved beside each. Run the caliper's inside jaws down each one; shrink at
that diameter is the engraved number minus what you read. Add the points to
`HOLE_SHRINK_CAL` and everything downstream re-derives.

### Root flares

A pin standing on a flat face meets it in a square corner, and that corner is
where a printed column breaks: the layer bond carries the whole bending moment
with nothing to spread it into. Every pin that has room now rises out of a
1.5 mm tapered skirt, sized to the largest its own mating clearance allows as
printed:

| pin | root | limited by | clearance left |
|---|---|---|---|
| guide post | Ø5.08 → Ø5.58 | the spring's Ø5.80 bore sliding over it | 0.11 mm |
| board locator | Ø2.58 → Ø2.98 | the nest's Ø3.40 pass-through | 0.10 mm |
| probe collar | Ø3.08 → Ø3.58 | the nest's Ø4.00 probe window | 0.10 mm |

On the locator — the tallest thing on the plate — that is **1.54× the section
modulus** at the root. The registration pins get none: the nest leaves them
0.075 mm, and at Ø4.00 × 6.5 mm they are 1.6:1, the stoutest thing standing
there. Giving them one would mean relieving the nest's underside and
reprinting it.

**The nest does not change.** All three flares fit inside clearances that
already existed.

### The bore is stepped, and that is what sets the probe height

A counterbore exactly one head deep (2.5 mm) sits over a bore sized for the
sleeve's **body**. The head cannot enter the body bore, so it bottoms with its
top flush with the platform — the sleeve's Z is geometry, not how hard you
pushed.

That matters more than it sounds. `PIN_PROTRUSION` is the number the entire
stack-up derives from, and until this was stepped the lead-in printed at Ø1.18
and the bore at Ø0.98 — both at or over the Ø0.98 head — so the sleeve slid
straight through and its height was set by feel.

The sleeve is then held at two places — the counterbore on its head and the
body bore on its body, 5.25 mm apart at 0.020 mm radial — and it is the
distance between those two that limits tilt, not either one alone. The whole
chain totals 0.442 mm worst case and 0.193 mm RSS against a 0.500 mm budget;
`verify.py` prints every link.

## The P100 variant

The default build is a **P50-B1 probe in an R50-2S receptacle**. Setting
`JIG_PINS=P100` builds for a **P100-B1 in an R100-4S** instead — a much larger
pin, and not a drop-in.

```bash
cd cad
JIG_PINS=P100 python3 jig.py       # -> cad/out/p100/
JIG_PINS=P100 python3 verify.py
python3 tools/compare_families.py  # which parts actually change
```

**It is not a base plate swap.** Two things force the rest:

The P100 probe stands **8.35 mm** out of its receptacle where the P50 stands
3.35 — 2.00 mm of tip cone plus 6.35 mm of Ø1.0 plunger rod, the whole of its
Ø1.36 barrel disappearing into the receptacle's 25.00 mm tube. Since the seat
height is `NEST_T + COMPRESSION − PIN_PROTRUSION` and nothing else in that
expression may move, the probe seat goes from **3.85 mm above** the hard-stop
plateau to **0.75 mm below** it. The plate stops growing a platform and gets a
relief instead — which is the easy half, and it also means no bottom-side
component can reach the plateau, so all the platform relief cutting disappears.

The hard half is that the R100 receptacle is **39 mm long** against the R50's
17.5. Its tail lands at z = −39.75, which is 22 mm past where the ST-Link's
roof used to be. Nothing in plan can move — the probes are where the board's
test points are — so the ST-Link moves out from under them into −Y and the box
grows by just enough to take it. That leaves a clear 39 mm-wide channel along
+Y with the full depth of the stand under it, which is where the tails and the
loom live.

| | P50 | P100 |
|---|---|---|
| probe stands proud of the receptacle | 3.35 mm | 8.35 mm |
| probe seat | 3.85 mm **above** the stop | 0.75 mm **below** it |
| working stroke | 1.20 of 2.65 mm | 1.60 of 3.50 mm |
| clamp load, closed | 10.0 N | 15.0 N |
| counterbore | Ø0.98 × 2.5 mm | Ø1.90 × 7.5 mm |
| body bore, as modelled | Ø1.35 | Ø1.85 |
| body bore, as printed | Ø0.90 × 8.0 mm | Ø1.71 × 5.0 mm |
| counterbore, as modelled | Ø1.35 | Ø2.00 |
| hole shrink, counterbore / body bore | 0.37 / 0.45 mm | 0.10 / 0.13 mm |
| fit gauge range | 1.30–1.75 | 1.80–2.25 |
| base plate | 8 mm thick | 14 mm thick |
| outline | 145 × 91 mm | 145 × 101 mm |
| lid screws | M3 × 12 | M3 × 16 |
| tail proud of the plate | 5.65 mm | 25.75 mm |

The body bore lands at **Ø1.71 as printed**, against the vendor's own stated
drilling size of 1.70 mm for this receptacle — the same 0.04 mm of diametral
clearance the P50 bore uses, landing within 0.01 mm of what the vendor
recommends for a drilled plate. (An earlier draft of this page called that an
independent check on the print model. It is not: `body + 0.04` is a design
rule and the algebra cancels the shrink out entirely, so it says nothing about
whether the print model transfers. The agreement with the vendor is still
worth having; it is just evidence about the clearance rule, not the printer.)

**`nest` and `cover` are unchanged** — identical volume, bounding box and
topology in both families, which `tools/compare_families.py` checks rather than
asserts. Print a new `base_plate`, `stand` and `fit_gauge`; keep the rest.

The P100's thinnest collar is **0.826 mm**, between VDD_3V3 and SWDIO 4.27 mm
apart — more than the P50's 0.35 mm, because with the seat recessed there is no
island to be cut back and the wall is shared with the neighbouring bore instead.

**Calibrate first, as always**, on the P100 gauge: it steps 1.95 to 2.40 and you
are looking for the bore an R100 head just enters.

### What to measure before printing a P100 plate

The receptacle's head bottoms on a shoulder at a **fixed** depth, so the probe
tip ends up at

```
(seat − RECEPT_HEAD_L) + head_as_measured + protrusion_as_measured
```

which means an error in **either** `RECEPT_HEAD_L` or `PIN_PROTRUSION` lands on
the working stroke one for one. Those two are the pair the whole stack-up rests
on, and both are read off the vendor drawing rather than measured. Their
combined error has to stay inside **−0.80 / +0.85 mm**, which is the 1.60 mm
working stroke moving between the 0.80 mm minimum and 70 % of the 3.50 mm full
travel.

| Measure | Model | How | Window |
|---|---|---|---|
| **`PIN_PROTRUSION`** | 8.35 | Seat a probe in a receptacle, measure the assembly's overall length, subtract the bare receptacle's. That difference is how far the tip stands proud. | see above |
| **`RECEPT_HEAD_L`** | 7.5 | Length of the enlarged section at the top, from the top face down to where the OD drops to the plain Ø1.67 body. This is the counterbore depth. | see above |
| `RECEPT_HEAD_D` | 1.90 | OD of that top section | 1.84–1.92 |
| `RECEPT_BODY_D` | 1.67 | OD of the plain tube | 1.55–1.69 |
| `PIN_STROKE_MAX` | 3.50 | Probe free length minus its length pressed fully home | ≥ 2.29 |
| `RECEPT_LEN` | 39.0 | Overall | 16.25–47.25 |

`PIN_BORE_D` is already done: the gauge read **2.00**.

The fit gauge reads `RECEPT_HEAD_L` for you as a by-product: its bores are
blind and exactly `RECEPT_HEAD_L` deep, so push a receptacle in **head first**
and the step where it drops to the body diameter should come out flush with the
coupon's face. Proud or sunk by *x* means your head is longer or shorter by *x*.

Then hand the numbers to the checker, which reports each against its window,
combines the two that matter, and tells you whether it is a model correction or
a reprint:

```bash
JIG_PINS=P100 python3 tools/check_pins.py \
    --protrusion 8.4 --head 7.6 --head-dia 1.91 --body-dia 1.68
```

`STLINK_CASE` and the four `CLAMP_*` numbers are unchanged from the P50 build,
but the P100 plate is a new print with new insert positions — so if you never
verified `CLAMP_SPINDLE_TO_ROW` (24.6 mm, spindle axis to the nearer mounting
row, inferred from the drawing), do it now, because fixed inserts give up the
fore-and-aft trim the clamp's own slots allowed.

## Assembly

1. Calibrate `PIN_BORE_D` with the gauge, measure your ST-LINK/V2 into
   `STLINK_CASE`, and only then print the parts.
2. Press an **R50-2S sleeve** (P100: **R100-4S**) into each bore from the top, tail first, until
   its head bottoms in the counterbore — its top will then be flush with the
   platform. The tail projects 5.7 mm below the deck into the wire bay. The
   counterbore locates and grips it; it does not necessarily retain it against
   a pull — see Wiring.
3. With the plate **off the stand and turned upside down**, solder a wire to
   each sleeve tail, then wick a drop of thin CA into each sleeve/bore joint to
   lock it. Label the wires as you go.

   This is why the plate is a separate part. Inverted on the bench it is a flat
   surface with seven 5.7 mm stubs standing up out of it and nothing within
   30 mm of any of them. Fused to the stand, the same joints sat 22 mm down a
   22 mm slot.
4. Melt in all **eight M3 heat-set inserts** — four in the clamp deck on top of
   the tower, four in the stand's corner bosses. Set your iron to about 240 °C
   for PETG, press each one in square, and let it set before loading it.

   Then bolt the GH-201 down with M3 × 12. Its holes are Ø4.0 × 5 mm deep with
   5 mm of solid tower underneath; load is only about 4 N per bolt, so this is
   far stronger than it needs to be — the inserts are for a clean repeatable
   thread, not strength.
5. Drop the **ST-LINK/V2** into the stand between the four floor ribs, feed its
   USB cable out through the hole in the +X wall, and plug the probe loom onto
   its 20-pin header (table below). Bring the 3.3 V feed in through the slot on
   the far side from the clamp and zip-tie it.
6. Lower the plate onto the stand and fit the four **M3 × 12** (P100: **M3 × 16**, for the thicker plate) into the corner
   inserts. Heads sit in Ø6.4 × 3 mm counterbores, flush below the plateau.

   These are inserts rather than screws cut straight into the plastic because
   the plate comes off every time you service the wiring or the ST-Link, and an
   M3 self-tapped into PETG does not survive many cycles. The clamp load is
   internal anyway — the spindle presses the cover down, the springs push the
   plate down by the same amount — so the screws only stop the lid shifting.
7. Push a **P50-B1 probe** (P100: **P100-B1**) into each sleeve until it seats. Tips should now
   stand 3.35 mm proud of the platform.

   This has to happen **before** the nest goes on: once it does, each sleeve
   top is at the bottom of a Ø4 hole 6.8 mm down, and with the board over it
   there is no way to push a Ø0.68 probe in axially.
8. Drop a spring into each of the four counterbores, over the guide posts, then
   lower the `nest` on. It passes over the two locator pins and the two
   registration pins without touching either.
9. The board drops onto the **base plate's** locator pins, through the nest, and
   seats on six nest bosses — one at each of its own mounting holes — plus the
   SWD tab and both flex necks, which carry no bottom-side parts at all. MH1 and
   MH4 at Ø2.10 locate it; there are no secondary pins.

   The pins are on the base plate rather than the nest so the board registers directly
   to the part that holds the probes: worst case 0.442 mm rather than 0.674 mm,
   against 0.5 mm of usable pad. They are stepped — Ø3.00 up to the seat, then
   Ø2.10 — so only 6 mm stands proud, at 2.9:1 rather than 5.7:1.

10. Adjust the clamp spindle. It presses **downward** from the clamp's mounting
   plane, and the deck sits at z = 20 mm against a cover top of 13.4 mm, so the
   spindle should end up about 6.6 mm proud — mid-range on its thread. Set it so
   the handle closes with a firm over-centre snap and the nest is driven fully
   onto its hard stop, then confirm with the continuity check below. If the
   handle closes limply, the spindle is too high and the nest is not bottoming.

## Wiring

Solder with the plate **off the stand and inverted** — seven free-standing
stubs on a flat surface, nothing within 30 mm of any of them.

The SWD loom does not leave the assembly: it runs from the tails down to the
ST-Link's 20-pin header inside the stand. Only the external 3.3 V feed uses the
slot in the far wall, and only the USB cable leaves the box.

The tails sit on a 4.3 mm minimum pitch, so use **30 AWG silicone wire**
(≈0.8 mm OD) rather than 26 AWG. Current is a non-issue — the MCU draws tens
of milliamps and each probe is rated 3 A — and the thinner wire makes the
cluster far easier to work in. Run the loom out through the slot on the far
side from the clamp and zip-tie it to the divider post; that post, not the
solder joints, should take any pull on the cable.

| Probe | Net | ST-Link | Note |
|---|---|---|---|
| 1 | SWDIO | SWDIO | |
| 2 | SWCLK | SWCLK | |
| 3 | NRST | NRST | gives connect-under-reset |
| 4 | SWO | SWO | optional, trace output |
| 5 | GND | GND | also the 3.3 V supply return |
| 6 | VDD_3V3 | VDD / VAPP sense | |
| 7 | VDD_3V3 | external 3.3 V feed | second pin doubles the current capacity. The ST-LINK/V2's VAPP pins are a voltage **sense** input — the dongle does not source power, so this comes in through the wall slot |

**Power:** feeding the VDD_3V3 test points back-powers the board's 3.3 V rail
directly, downstream of its own regulator. Do not apply VIN at the same time
unless you have confirmed the regulator tolerates being back-fed. With only
3.3 V applied, the gate drivers and CAN transceiver stay unpowered, which is
what you want for flashing the MCU. Each probe is rated 3 A, so two VDD_3V3
pins is far more headroom than the few tens of mA the MCU needs.

## Using it

1. Open the clamp, lift the cover off by its tab.
2. Drop the board into the nest recess; it seats on two locator pins.
3. Replace the cover — it drops over all four guide posts and can
   only go on one way round.
4. Close the clamp. The nest travels 3 mm to a hard stop.
5. Flash. Open the clamp; the springs lift the board clear of the probes.

## Checks before the first run

| Check | Expected |
|---|---|
| Continuity, each probe to its net with the clamp closed | < 1 Ω |
| Continuity with the clamp open | open circuit |
| Probe tips proud of the platform, clamp open | 3.35 mm |
| Nest lift, clamp open | 3.0 mm |
| Spring solid height (compress one fully) | under 10 mm |
| Spindle lands in the cover dimple | within Ø8 mm |
| Clamp force at close | roughly 1.6 kg |

## Tuning

Two numbers are worth verifying against the parts you actually received.
Both live in [`cad/params.py`](../cad/params.py); change one and re-run
`python3 jig.py && python3 verify.py`.

**`PIN_PROTRUSION` (3.35 mm)** — how far the P50-B1 tip stands above the
seated R50 sleeve. Measure it with the probe pressed into a sleeve. This one
number sets the platform height and therefore the probe compression; the
verification script re-derives everything from it. If your probes measure,
say, 3.6 mm, the platform simply drops 0.25 mm.

**`PIN_BORE_D` (1.20 mm) and `PRINT_HOLE_SHRINK` (0.22 mm)** — calibrated
together from the fit gauge, as above. These are the two numbers that depend on
your printer rather than on the parts, and every other fit in the design is
computed from the second one.

**Known residual risk, not designed out:** the body bore is Ø1.12 × 8 mm, a
7:1 aspect vertical hole, which is what FDM is least good at. The gauge
calibrates the counterbore but says nothing about whether the bore beneath it
comes out tapered. If a sleeve seats cleanly in the gauge but will not bottom
in the plate, that is the cause — shorten `PIN_BORE_L` to 6 mm and reprint the
plate; the cost is 0.003 mm of extra probe tilt against a 0.500 mm budget.

**Two probe collars are thin by necessity.** SWDIO and SWCLK sit 0.95 and
1.05 mm from the inflated footprint of the tallest bottom-side component, so
their collars are 0.35 and 0.45 mm on that side over the top 0.8 mm — about one
extrusion. Two thirds of each counterbore is still fully enclosed. This is set
by where the component actually is, not by a choice in the model; the other
five collars are the full Ø3.0.

**`CLAMP_SPINDLE_TO_ROW` (24.6 mm) — measure this before printing the plate.**
It is the distance from the spindle axis to the nearer of the two mounting-hole
rows, and it decides where the spindle lands on the cover. Fixed inserts have no
fore-and-aft slop to absorb an error, unlike the sliding nuts they replaced.
24.6 mm is inferred from the drawing (19.6 mm spindle-to-plate plus about 5 mm
plate-edge-to-hole), **not measured**, so check it. `verify.py` reports where
the spindle would land against the cover's Ø8 mm dimple.

**`CLAMP_HOLE_DX` / `CLAMP_HOLE_DY` (15.9 / 11.1 mm)** — the GH-201 mounting
hole pattern, also read off the drawing. Check with calipers.

`TOWER_TOP_Z` (20 mm) sets how high the clamp sits. Reach is adjustable — the
deck slots give 8 mm on top of the clamp's own, and the spindle covers height —
but the deck height itself is part of the base plate, so changing it means
reprinting the plate.

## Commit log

2026-08-30 Add SWD pogo programming jig for the CANServo_Driver board
    A five-part 3D-printed spring-nest fixture that probes the seven bare-copper
    test points on the underside of the board, with no PCB in the fixture.
    Board geometry is extracted rather than transcribed. cad/tools/extract_board.py
    polygonises the Edge_Cuts gerber (snapping a 9 um export gap that otherwise
    leaves the profile open) and recovers the outline, the eleven cutouts and the
    test points; extract_parts.py pulls per-component keep-out volumes from the
    KiCad STEP export. Both write JSON in a jig frame whose origin is the centroid
    of the four 2.2 mm holes on the main rigid section, and jig.py builds entirely
    from that JSON, so a new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
    [base_plate.step, base_plate.stl, clamp_riser.step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]
2026-08-30 Guard the keep-out model and check the probe hardware fit
    extract_parts.py now refuses to emit board_parts.json if any board-spanning
    solid protrudes past a face by more than the film threshold. Those solids fall
    into neither the top nor the bottom list, so a through-hole lead on a future
    board revision would silently vanish from the clearance model. On V0.4 all 168
    spanning solids are via and pad plating within 0.04 mm of a face, which is what
    lets verify.py's bounding-box keep-out stand as a proof of clearance rather
    than a sample of it.
    Also adds seven checks that the R50/P50 hardware actually fits the bores it is
    given - sleeve tail projection into the wiring space, drilled bore against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
    [base_plate.step, clamp_riser.step, cover.step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]
2026-08-30 Replace the render pipeline with a software z-buffer rasteriser
    The painter's-algorithm renderer sorted whole parts, then triangles by
    centroid depth, and both mis-ordered the stand's large flat faces against the
    base plate - the earlier assembly image showed the pedestal painted over the
    plate above it. This rasterises properly: orthographic projection, backface
    culling, per-pixel depth test, Lambert shading, 2x supersampling, and a depth
    discontinuity pass that draws silhouettes and creases. It also fixes a sign
    error in the diffuse term that had every surface sitting at ambient.
    Twelve views replace the five: four isometrics, three orthographic elevations,
    an exploded view, clamp open vs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
2026-08-30 Make the stand one piece and open up the wiring space
    The clamp riser was a separate block bolted to a stub on the stand. It is now
    the same shell: the pedestal walls carry straight up to the mounting deck, and
    the step where they meet the frame is simply where the base plate slots in
    beside them. Four printed parts instead of five, and nothing to work loose
    under clamp load.
    The tower stays solid up to a shallow captive-nut channel under the deck. A
    full-height cavity prints fine but would leave an M4 nut to fish for 40 mm down
    a hole; the channel is open at the back face so a nut slides in from outside
    and its walls stop it turning. The deck slots run 8 mm longer than the GH-201's
    own, so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
    [base_plate.step, clamp_riser.step, clamp_riser.stl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]
2026-08-31 Drop the drilling step, widen the stand, simplify the nest
    Three changes, each of which removed work rather than adding it.
    No post-print machining. The probe bores now print to final size, with the
    printer's own hole shrinkage calibrated out once instead of drilled out every
    time: fit_gauge is a coupon with eight bores from 0.85 to 1.20 mm, printed in
    the material the plate will use, and the hole an R50 sleeve just enters becomes
    PIN_BORE_D. The bore also grew from 6 mm to 9 mm of engagement on a 17.5 mm
    sleeve, which is what makes a calibrated-but-imperfect fit acceptable: at
    0.04 mm of play the tip lands 0.28 mm from pad centre against a 0.35 mm budget,
    and verify.py now prints that sum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
    [base_plate.step, base_plate.stl, cover.step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]
2026-08-31 Raise the clamp deck and move the board locators to the base plate
    The GH-201 drawing settles the open question from the audit, and the answer was
    that the jig could not be clamped. The spindle sits at its mounting plane and
    adjusts downward only, so the deck at z=12.00 was 1.43 mm BELOW the cover top it
    had to press. TOWER_TOP_Z goes to 20.00, putting the spindle 6.6 mm down from
    its plane - mid-range on a 15 mm assembly - with the arm around 27 mm, clear of
    both the open cover at 16.43 and the guide posts at 16.00. TOWER_SOLID_Z rises
    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
    [base_plate.step, base_plate.stl, cover.step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]
2026-08-31 Bolt the clamp into M3 heat-set inserts
    Replaces the captive-nut channel with four blind Ø4.0 x 5 mm holes for M3
    heat-set inserts in the clamp deck, sized on the Kadrick profile (Ø4.5 knurl,
    Ø3.9 tip) by the usual between-the-two-diameters rule, with 5 mm of solid tower
    left underneath. Load is about 4 N per bolt, so this is about a clean
    repeatable thread rather than strength.
    Doing it surfaced a second problem the nut channel had been hiding. Sliding
    nuts absorbed fore-and-aft error in the mount position; fixed inserts do not,
    so the position has to be right. Working back from where the spindle must land
    - the dimple at the centroid of the cover's contact pads - the mount needed to
    mo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
    [base_plate.step, cover.step, fit_gauge.step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]
2026-09-09 Set probe bore to the measured 1.20 mm calibration
    The fit gauge came back with the R50 sleeve entering the 120 bore and
    nothing smaller, so the printer is rendering a small vertical hole about
    0.22 mm under nominal. The base plate was still boring the 1.00 mm
    placeholder, which would have come out near 0.78 mm -- too tight for a
    0.98 mm sleeve head to enter at all.
    - PIN_BORE_D 1.00 -> 1.20.
    - GAUGE_BORES moved from 0.85-1.20 to 0.90-1.35. The result landed on the
    old top slot, so the gauge never bracketed it from above and could not
    distinguish a press fit from a loose one; verify.py's "gauge brackets
    the modelled bore" check catches exactly this and was failing.
    - PIN_LEAD_D left a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
    [base_plate.step, base_plate.stl, cover.step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]
2026-09-10 Free the guide posts, stiffen the locators, centre the clamp
    Four mechanical fixes from bench feedback on the first print.
    Guide posts bound. The 0.30 mm modelled clearance (Ø5.00 post, Ø5.30 hole)
    was exactly consumed by this printer's 0.22 mm hole shrink plus ~0.08 mm of
    boss growth -- an as-printed line-to-line press fit. Four posts in four
    holes is also over-constrained, so any scaling difference between the parts
    jams it however round the holes are. POST_HOLE_D 5.30 -> 5.80, which prints
    0.50 mm diametral, and the locating job moves to two dedicated pins: round
    at the primary, slotted at the secondary, which is kinematically exact.
    Board locator pins were 12 mm of Ø2.10 standing fr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
    [base_plate.step, base_plate.stl, cover.step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]
2026-09-10 Fuse the deck and stand into one body, house the ST-LINK/V2
    The deck and the stand were two parts bolted together with four M3. With the
    ST-Link wired in permanently they are never separated in service, so the
    screws were pure assembly cost. They are now one printed part, `body`.
    Printing it as one piece means the deck underside spans the wire bay, which
    was a 34 mm bridge. The bay walls corbel inward at 45 degrees over the last
    6 mm -- printable without support -- cutting the span to 22 mm, which still
    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
    [body.step, body.stl, cover.step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]
2026-09-10 Split the plate off again for bench soldering; rehouse the bigger ST-Link
    Two things forced a re-layout.
    The probe tails were unworkable. Fused to the stand, soldering seven 5.65 mm
    stubs on a 4.3 mm pitch meant reaching 22 mm down a 22 mm slot -- and the
    corbel pinched the opening at exactly the point you had to reach through.
    That was the cost of integration, and it is not worth paying. The plate is a
    separate part again: inverted on the bench it is a flat surface with seven
    stubs standing out of it and 0.0 mm3 of material within 30 mm of any of them.
    The ST-Link measured 100 x 50 x 30 rather than 97 x 32 x 17, which fits
    nowhere in the old envelope -- 16 mm too wide and 10 mm too tall u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
    [base_plate.step, base_plate.stl, cover.step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]
2026-09-10 Blend the stand's corner bosses into the walls; use inserts for the lid
    The bosses were bare cylinders dropped next to the corners, and none of them
    joined the wall properly. The two -Y bosses met the inner wall face at
    exactly 0.00 mm -- tangent, so the two surfaces close to a zero-degree wedge
    that leaves a 0.11 mm gap 1 mm from the tangent point and 0.44 mm at 2 mm.
    No 0.4 mm nozzle fills that; it prints as an open groove and a stress riser.
    The two +Y bosses were worse: 1.00 mm clear of the wall, free-standing
    pillars with a slot behind them.
    Fixed by building the wall ring and the four bosses as ONE 2D region and
    morphologically closing it by 3 mm, which fillets every reflex corner bet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
    [base_plate.step, cover.step, fit_gauge.step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]
2026-09-10 Fix the defects the adversarial review found, and make the checks bite
    Three reviewers attacked the design; this fixes what they found and rewrites
    the checks that were passing regardless of the geometry.
    GEOMETRY
    Cover was holed through at the spindle. Sphere(COVER_DIMPLE_R=4.0) centred on
    the top face of a COVER_T=4.0 plate reaches exactly the underside: 0.000 mm
    of material at the one point the whole 16 N clamp load lands, and cover.stl
    was non-manifold there. The dimple is now a shallow dish cut to an explicit
    COVER_DIMPLE_DEPTH, leaving 2.80 mm.
    TRAVEL was fiction. Nothing limits upward travel -- the posts are plain
    cylinders with no head -- so the rest position is wherever the sprin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
    [base_plate.step, base_plate.stl, cover.step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]
2026-09-10 Bring the docs in line with the rebuilt design
    - Calibration: the gauge is now ten blind counterbores 2.5 mm deep, matching
    the feature it calibrates instead of an 11 mm through hole, and the
    procedure sets PRINT_HOLE_SHRINK alongside PIN_BORE_D. That second number
    is what every other fit derives from, so recalibrating without it left the
    guide posts, registration pins, locator shanks and insert holes sized for
    the previous machine.
    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
    [base_plate.step, cover.step, fit_gauge.step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]
2026-09-10 Widen the fit gauge pitch so a three-digit label fits
    At a 7.5 mm pitch the '135' label was 7.1 mm wide, leaving 0.4 mm between
    labels. Pitch 9.0 and a 4.0 mm font gives 1.6 mm. The coupon grows to
    95 x 14 x 5 mm, which is still under ten minutes of print time.
    Claude-Session: https://claude.ai/code/session_017mn8f7RxvGhE8RJ1vuZwC5
    [base_plate.step, cover.step, fit_gauge.step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]
2026-09-10 Exclude copper film from the exact verification path
    verify.py --full reported PCBA vs nest = 0.2801 mm3. Tracking it down: 45
    solids, every one exactly 0.04 mm thick at z 5.96..6.00, each wholly inside
    the nest seat. They are bottom-side copper pads and via rings -- the board
    resting on its own copper, which every PCB does.
    tools/extract_parts.py already excludes exactly this class at FILM_T = 0.12,
    so the fast path never saw them. The exact path included every solid in the
    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
2026-09-10 Drop the stale body.step/stl exports
    Left over from the revision where the deck and stand were one part. That part
    no longer exists -- PARTS_TO_BUILD emits base_plate and stand separately -- so
    the files were dead weight and, worse, a plausible-looking thing to hand to a
    slicer.
    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
    [base_plate.step, body.step, body.stl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]
2026-09-11 Add magfixture: a magnet test fixture for the encoder and hall sensor
    Holds the V0.4 board flat and presents a magnet to each of its two magnetic
    sensors.
    Both sensor positions are MEASURED, not transcribed. The KiCad STEP export
    labels each component with its footprint name, so tools/find_sensors.py reads
    them straight out of it: AS5600L-ASOM at (+46.81, +0.10) with its package top
    1.76 mm above the board, and the SOT-23 at (-23.25, +0.07) at 1.20 mm.
    Encoder: a Ø6 x 2.5 diametric magnet in a rotor journalled directly over the
    package, spun by finger. The 1.00 mm airgap -- inside the AS5600 datasheet's
    0.5-3.0 window -- is set by the rotor's own shaft length against a knob that
    lands on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
    [board_plate.step, board_plate.stl, encoder_gantry.step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]
2026-09-11 magfixture: one monolithic body, a column instead of posts
    The two Ø6 x 30 mm posts that carried the hall carriage broke off at the
    root. They were always going to: a printed cylinder lays its layer bonds
    square across the bending load, the pair gave 42 mm3 of section modulus,
    and a cylinder cannot be flared into the plate. They are replaced by one
    14 x 10 mm rectangular column on a gusset -- 228 mm3, 1.09 MPa at the root
    under a 10 N shove at the top of travel, a 23x margin on PETG's layer bond.
    The plate, the column and the encoder stand are now a single part. The
    stand also stops being a cantilever: two walls carry a deck, so the deck's
    underside is a bridge anchored at both ends rather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
    [board_plate.step, board_plate.stl, encoder_gantry.step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]
2026-09-15 cad: a P100 pin variant, selected with JIG_PINS
    Answering "can this just be a different base plate?" for a P100-B1 probe in
    an R100-4S receptacle: no, and the reason is worth writing down.
    The P100 probe stands 8.35 mm out of its receptacle where the P50 stands
    3.35 -- 2.00 of tip cone plus 6.35 of Ø1.0 plunger rod, the whole of its
    Ø1.36 barrel disappearing into the receptacle's 25.00 mm tube. The seat
    height is NEST_T + COMPRESSION - PIN_PROTRUSION and nothing else in that
    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
    [base_plate.step, base_plate.stl, cover.step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]
2026-09-15 cad: a measurement checker for the pogo hardware
    The P100 numbers came off a vendor drawing, and two of them -- RECEPT_HEAD_L
    and PIN_PROTRUSION -- land on the working stroke one for one, because the
    receptacle's head bottoms on a shoulder at a fixed depth. Their combined
    error has to stay inside -0.80/+0.85 mm or the probe either fails to make
    contact or bottoms out.
    tools/check_pins.py takes whatever you measured, reports each value against
    its window, combines those two, and says which params.py lines to change and
    whether the plate you already printed is still usable or has to be reprinted.
    Anything you leave out is reported as unmeasured rather than assumed good.
    docs/BUILD.md gains t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
2026-09-15 cad: hole shrink is a function of diameter, not a constant
    The P100 fit gauge read 2.00 on a Ø1.90 head -- 0.10 mm of shrink, where the
    P50 gauge read 1.20 on a Ø0.98 head for 0.22. Two measurements 0.92 mm apart
    in diameter, and shrink halves between them. That is the shape you would
    expect, a small hole losing more because the perimeter is laid on the inside
    of a tight curve, but the design was built on the single Ø1.2 figure.
    Carrying it across would have been silent and fatal: PIN_BODY_BORE_D is
    offset from PIN_BORE_D, so 2.00 would have modelled the body bore at Ø1.81
    and printed it at Ø1.59 -- an interference fit on a Ø1.67 sleeve that would
    never have gone in.
    So hole_shrink(d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
    [base_plate.step, base_plate.stl, cover.step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]
2026-09-18 cad: the P50 gauge was read with the probe, not the receptacle
    Which makes PIN_BORE_D = 1.20 an answer to a different question. The P50-B1's
    barrel is Ø0.68; the R50-2S's head is Ø0.98. So the bore was set 0.30 mm
    small, and on the bench no sleeve would seat -- not even in the old gauge's
    top slot at 1.35.
    That withdraws the Ø1.2 calibration point. What survives from it is a bound,
    not a value:
    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
    [base_plate.step, base_plate.stl, cover.step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]
2026-09-19 cad: hole shrink depends on depth, and that is what broke the receptacles
    The P50 gauge's two rows are the same diameters at different depths, so it
    measured the depth term directly:
    Ø1.35 x 2.5 deep took the Ø0.98 head, 1.30 not quite -> 0.37
    Ø1.35 x 8.0 deep took the Ø0.86 body with a little -> 0.45
    play, 1.30 not at all
    Ø2.00 x 7.5 deep took the Ø1.90 R100 head -> 0.10
    5.5 mm deeper costs 0.08 mm of printed diameter. The model had diameter only,
    and PIN_BODY_BORE_D was OFFSET from PIN_BORE_D on the assumption that both
    bores shrank alike -- so the plate went out with a body bore modelled 1.30,
    printing about Ø0.85 against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
    [base_plate.step, base_plate.stl, cover.step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]
